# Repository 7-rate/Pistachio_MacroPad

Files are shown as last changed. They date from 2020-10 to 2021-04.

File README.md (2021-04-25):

# Pistachio_MacroPad

[PistachioMacroPad](https://rates.booth.pm/items/2531312)の基板情報。

## 回路図
回路図は[こちら](./Pistachio_MacroPad_rev1.0/schema.pdf)<br>
必要な電子部品も上記から確認お願いします。

## 機械パーツ
ねじやスペーサなどのパーツはPistachioMacroPadと同じです。
Boothページよりご確認ください。

## プレート類
トッププレート、ボトムプレートの設計図面は[こちら](./CAD)

## ビルドガイド
PistachioMacroPadとほぼ同じです。<br>
[こちら](https://ratelog.net/pistachiomacropad-build-guide/)からご確認お願いします。

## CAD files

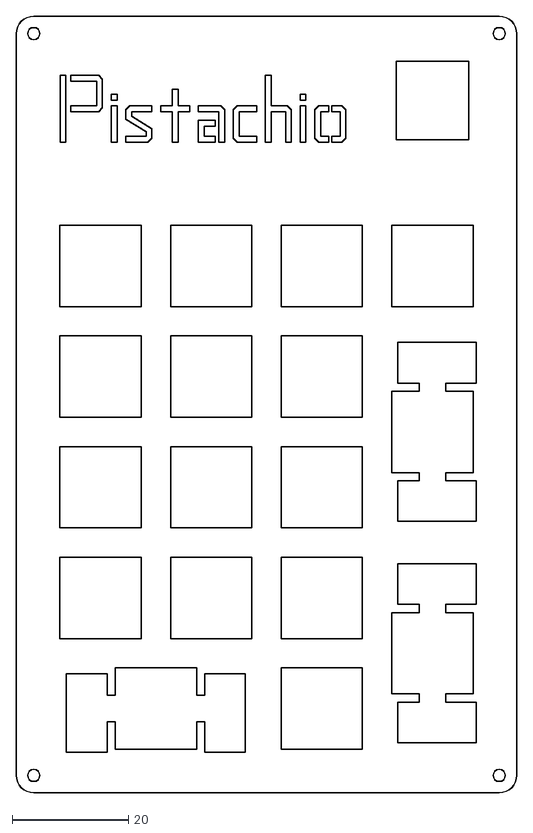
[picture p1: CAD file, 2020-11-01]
CAD/Plate_v2.dxf
86.1 x 133.7

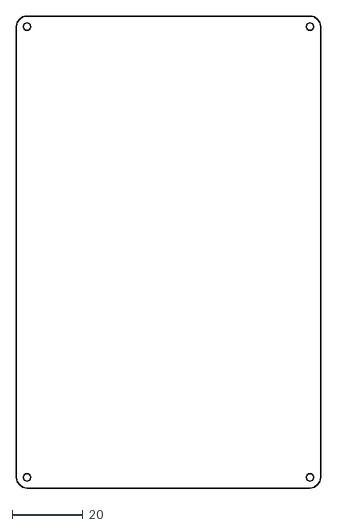
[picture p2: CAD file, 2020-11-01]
CAD/bottom.dxf
86.1 x 133.7

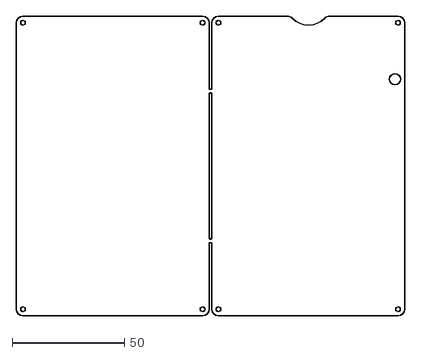
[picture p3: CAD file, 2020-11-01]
CAD/PCB_base_v2.dxf
173.3 x 133.7

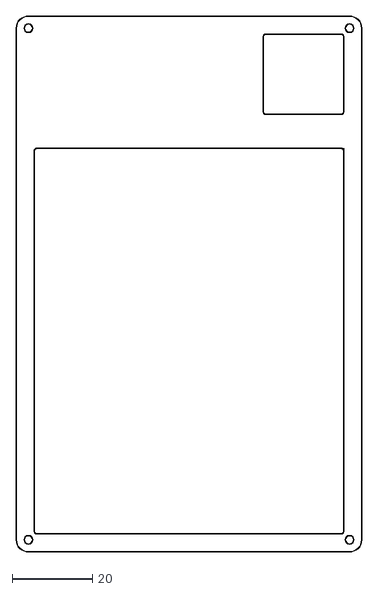
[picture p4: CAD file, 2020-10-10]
CAD/Top.dxf
86.1 x 133.7

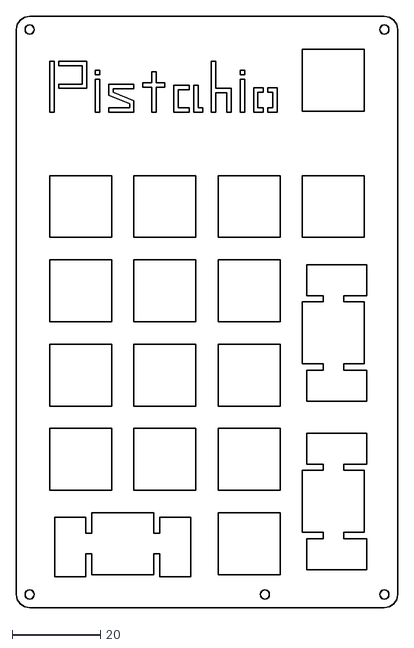
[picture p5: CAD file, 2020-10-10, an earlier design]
CAD/Plate.dxf
86.1 x 133.7

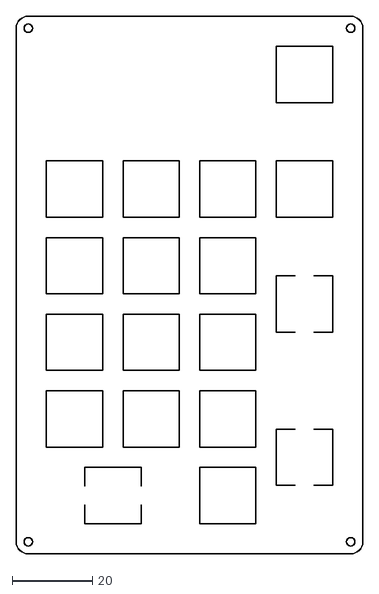
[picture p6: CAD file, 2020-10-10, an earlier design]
CAD/PCB_base.dxf
86.1 x 133.7

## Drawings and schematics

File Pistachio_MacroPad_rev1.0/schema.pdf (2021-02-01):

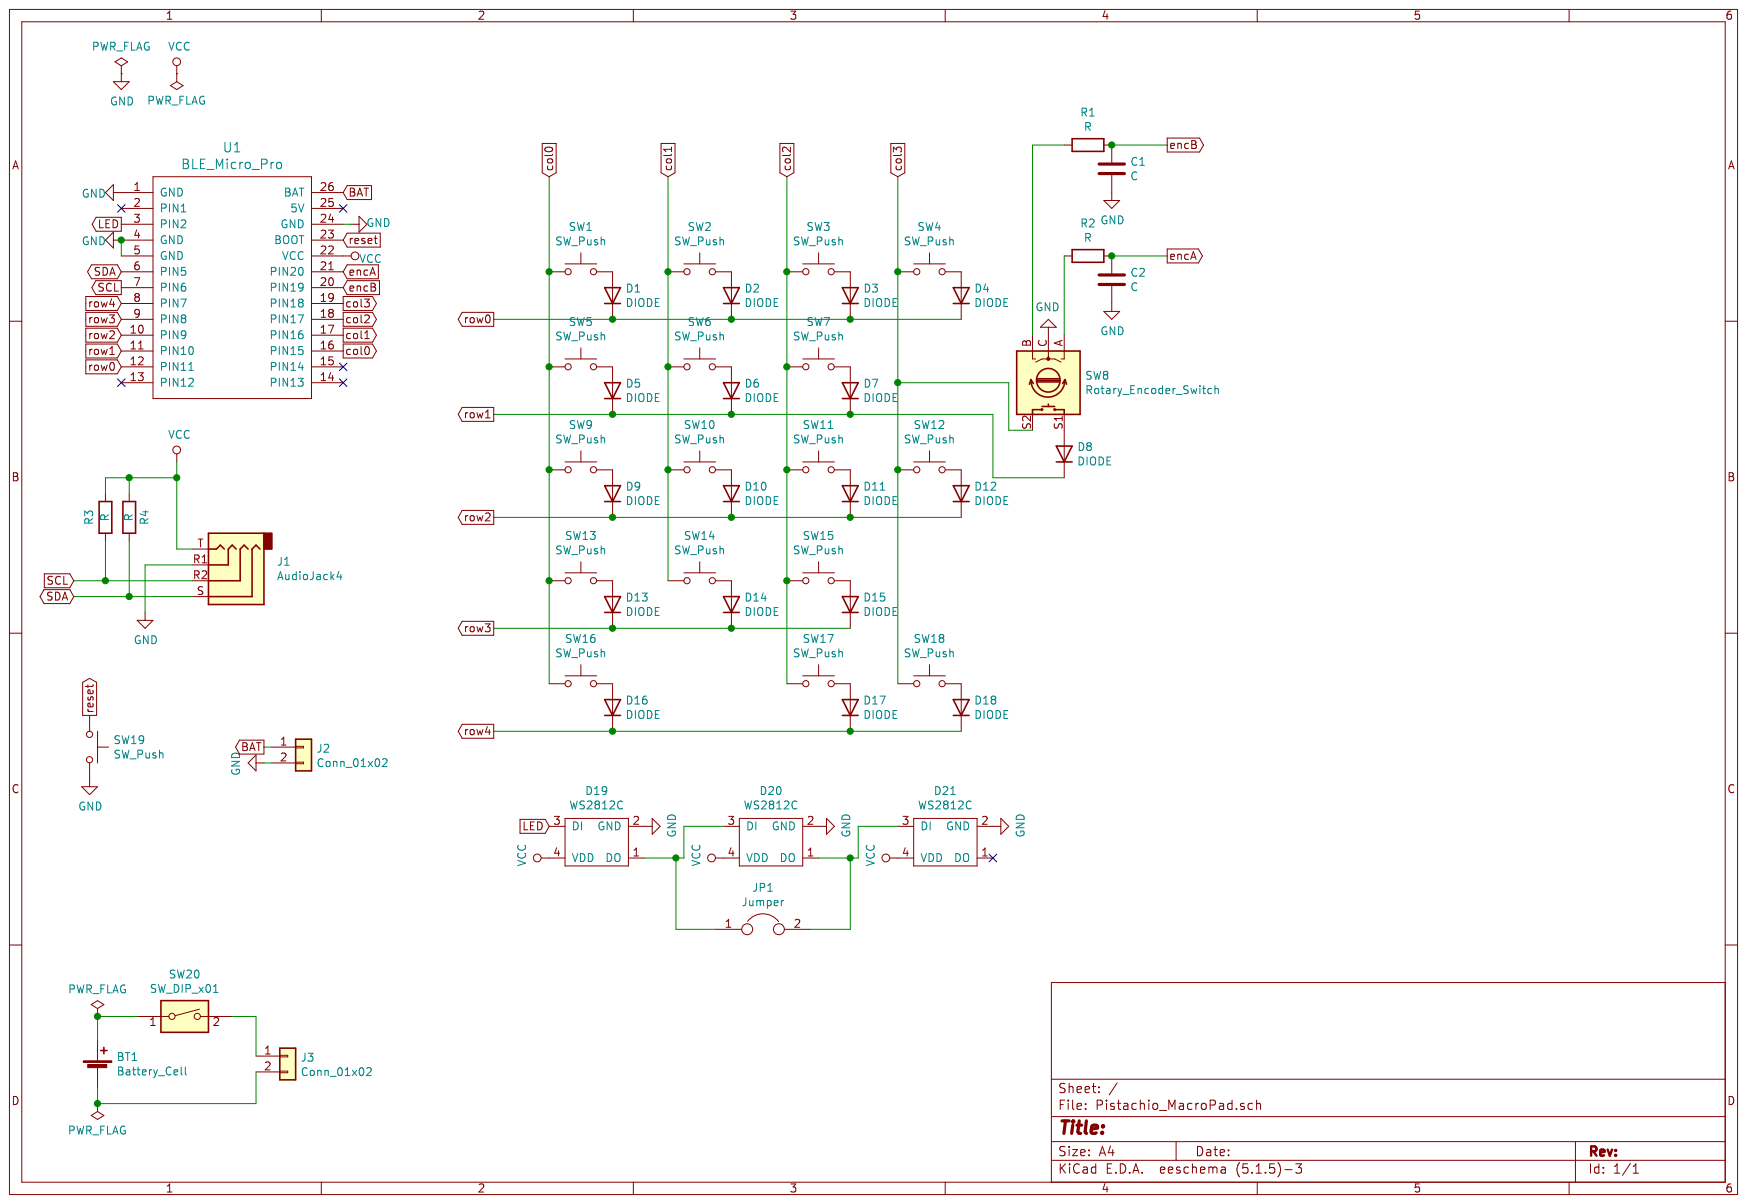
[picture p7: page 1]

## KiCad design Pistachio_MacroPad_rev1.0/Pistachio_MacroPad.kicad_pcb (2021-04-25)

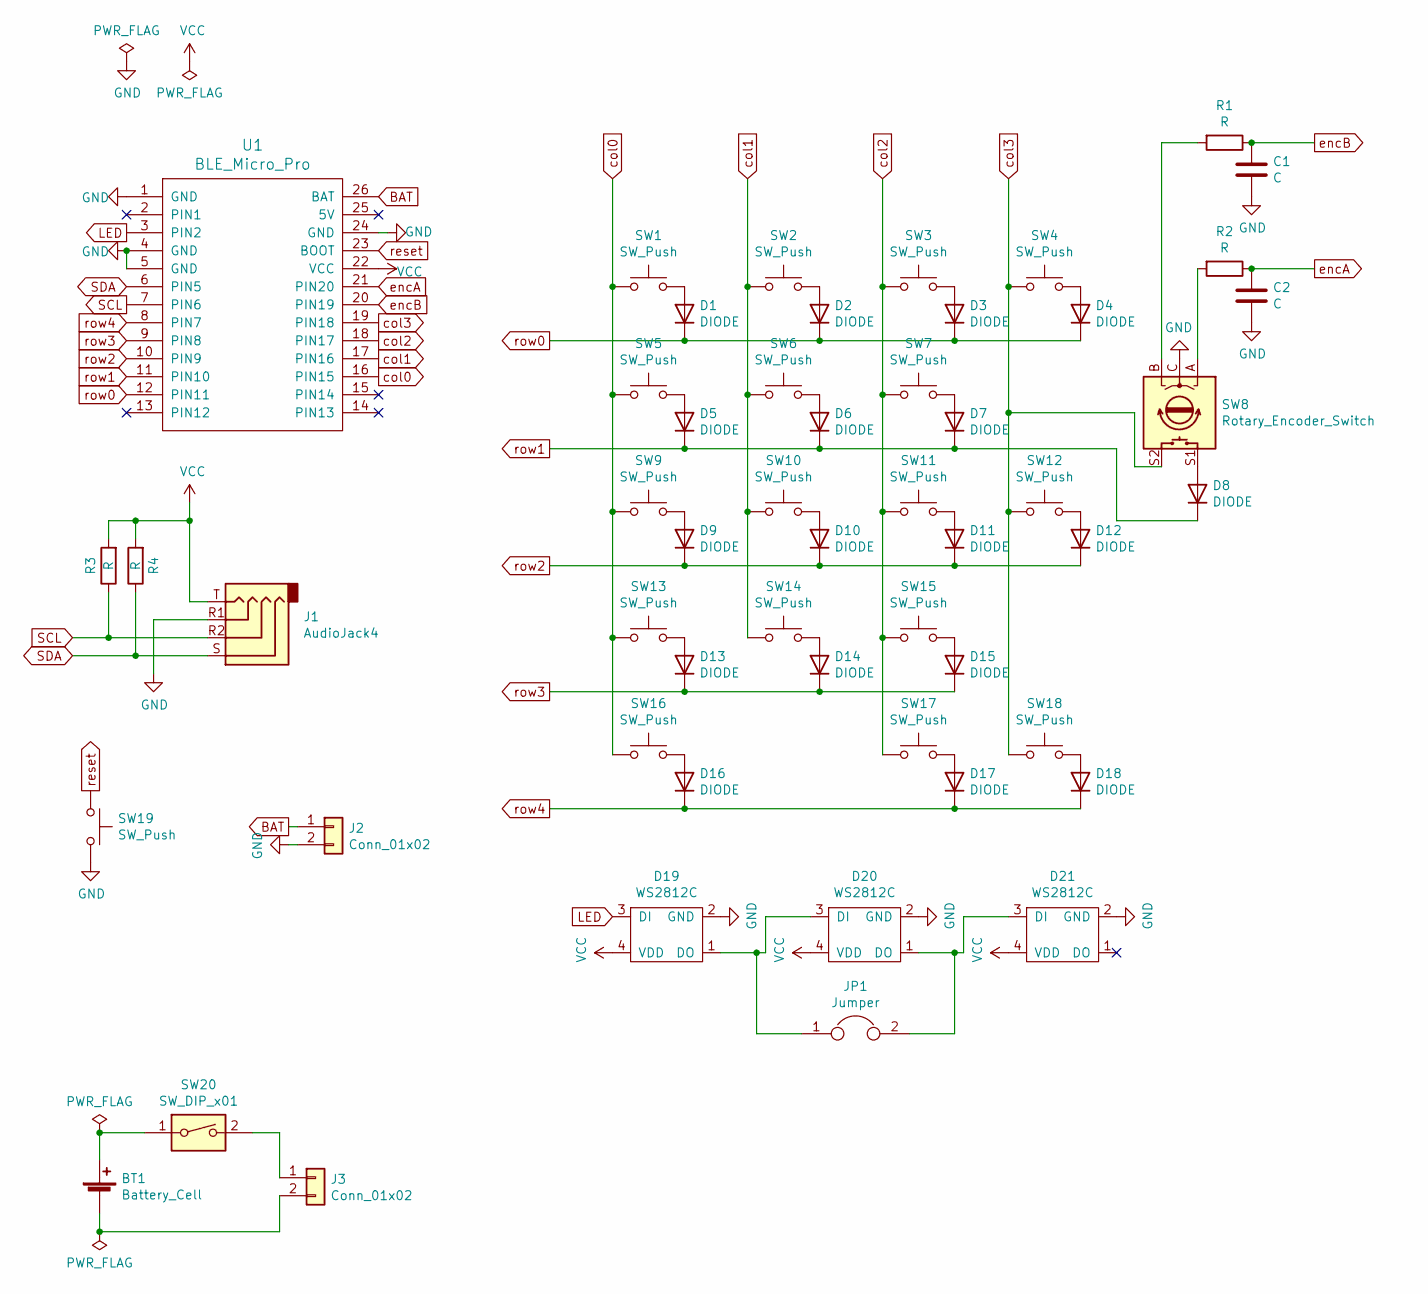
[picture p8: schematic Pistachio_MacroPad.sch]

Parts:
BT1: Battery_Cell; BAT_HLD-001
C1, C2: C; C_0603_1608Metric_Pad1.05x0.95mm_HandSolder
D1, D2, D3, D4, D5, D6, D7, D8, D9, D10, D11, D12, D13, D14, D15, D16, D17, D18: DIODE; D3_SMD_v2
D19, D20, D21: WS2812C; WS2812C-2020
J1: AudioJack4; MJ-4PP-9_1side
J2: Conn_01x02; S2B-ZR-3.4
J3: Conn_01x02; POWER_PAD
JP1: Jumper; SolderJumper-2_P1.3mm_Open_RoundedPad1.0x1.5mm
R1, R2, R3, R4: R; R_0603_1608Metric_Pad1.05x0.95mm_HandSolder
SW1, SW2, SW3, SW4, SW5, SW6, SW7, SW9, SW10, SW11, SW12, SW13, SW14, SW15, SW16, SW17, SW18: SW_Push; Kailh_socket_MX_optional
SW8: Rotary_Encoder_Switch; PEC12R-4xxxF-Sxxxx
SW19: SW_Push; ResetSW_1side
SW20: SW_DIP_x01; SlideSwitch_IS-2245S-G
U1: BLE_Micro_Pro; ProMicro_BLE

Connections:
BAT: J2.1, U1.26 (BAT)
GND: C1.2, C2.2, D19.2 (GND), D20.2 (GND), D21.2 (GND), J1.R1, J2.2, SW8.C, SW19.2, U1.1 (GND), U1.4 (GND), U1.5 (GND), U1.24 (GND)
LED: D19.3 (DI), U1.3 (PIN2)
unnamed: BT1.1 (+), SW20.1
unnamed: BT1.2 (-), J3.2
unnamed: D1.1 (A), SW1.2
unnamed: D2.1 (A), SW2.2
unnamed: D3.1 (A), SW3.2
unnamed: D4.1 (A), SW4.2
unnamed: D5.1 (A), SW5.2
unnamed: D6.1 (A), SW6.2
unnamed: D7.1 (A), SW7.2
unnamed: D8.1 (A), SW8.S1
unnamed: D9.1 (A), SW9.2
unnamed: D10.1 (A), SW10.2
unnamed: D11.1 (A), SW11.2
unnamed: D12.1 (A), SW12.2
unnamed: D13.1 (A), SW13.2
unnamed: D14.1 (A), SW14.2
unnamed: D15.1 (A), SW15.2
unnamed: D16.1 (A), SW16.2
unnamed: D17.1 (A), SW17.2
unnamed: D18.1 (A), SW18.2
unnamed: D19.1 (DO), D20.3 (DI), JP1.1
unnamed: D20.1 (DO), D21.3 (DI), JP1.2
unnamed: J3.1, SW20.2
unnamed: R1.2, SW8.B
unnamed: R2.2, SW8.A
SCL: J1.R2, R3.1, U1.7 (PIN6)
SDA: J1.S, R4.1, U1.6 (PIN5)
VCC: D19.4 (VDD), D20.4 (VDD), D21.4 (VDD), J1.T, R3.2, R4.2, U1.22 (VCC)
col0: SW1.1, SW5.1, SW9.1, SW13.1, SW16.1, U1.16 (PIN15)
col1: SW2.1, SW6.1, SW10.1, SW14.1, U1.17 (PIN16)
col2: SW3.1, SW7.1, SW11.1, SW15.1, SW17.1, U1.18 (PIN17)
col3: SW4.1, SW8.S2, SW12.1, SW18.1, U1.19 (PIN18)
encA: C2.1, R2.1, U1.21 (PIN20)
encB: C1.1, R1.1, U1.20 (PIN19)
reset: SW19.1, U1.23 (BOOT)
row0: D1.2 (K), D2.2 (K), D3.2 (K), D4.2 (K), U1.12 (PIN11)
row1: D5.2 (K), D6.2 (K), D7.2 (K), D8.2 (K), U1.11 (PIN10)
row2: D9.2 (K), D10.2 (K), D11.2 (K), D12.2 (K), U1.10 (PIN9)
row3: D13.2 (K), D14.2 (K), D15.2 (K), U1.9 (PIN8)
row4: D16.2 (K), D17.2 (K), D18.2 (K), U1.8 (PIN7)

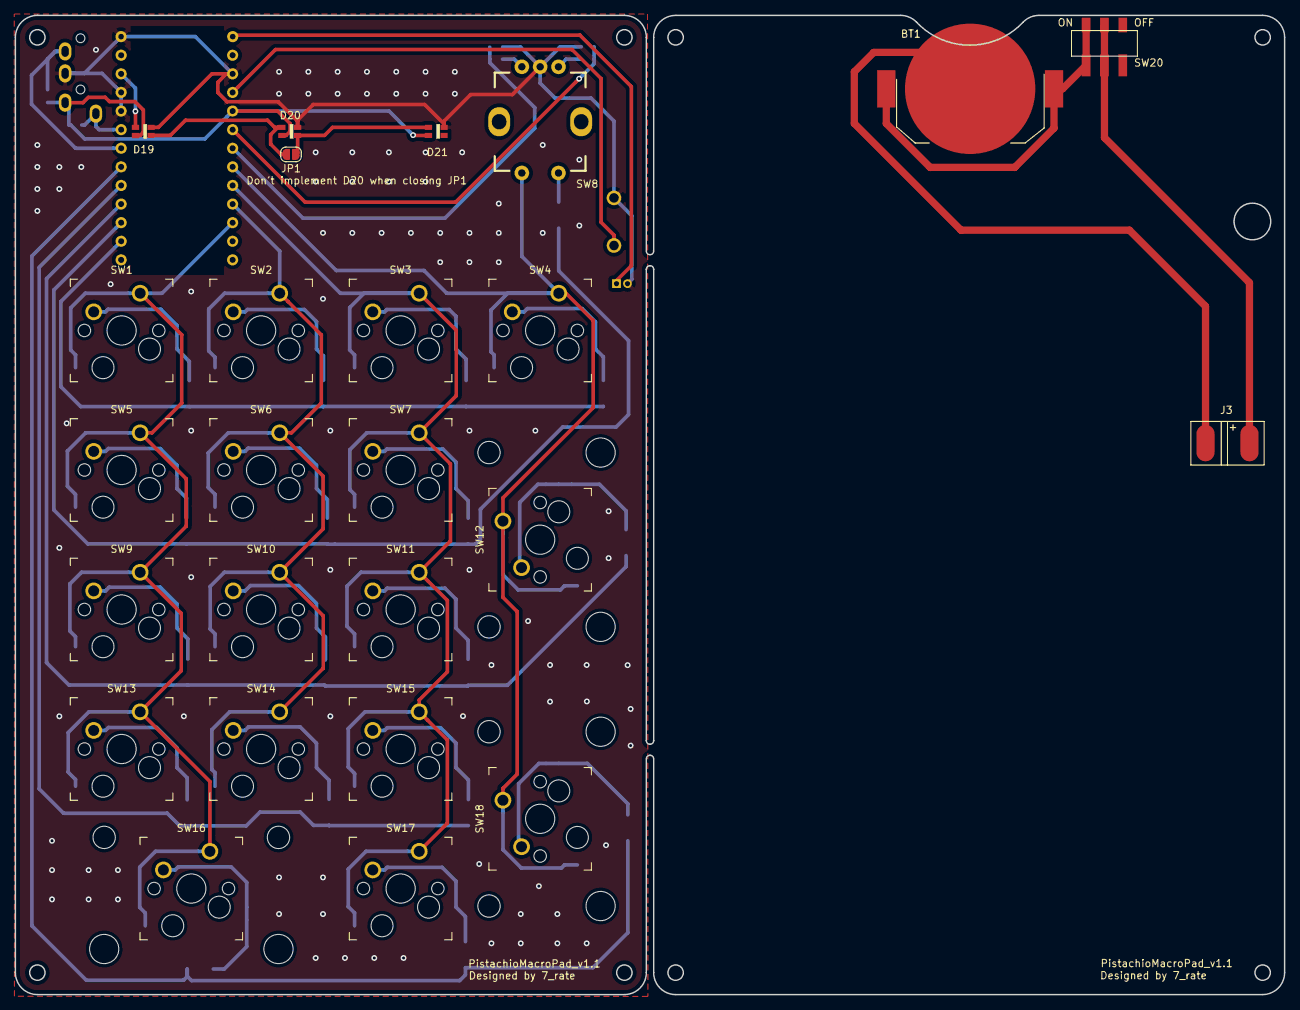
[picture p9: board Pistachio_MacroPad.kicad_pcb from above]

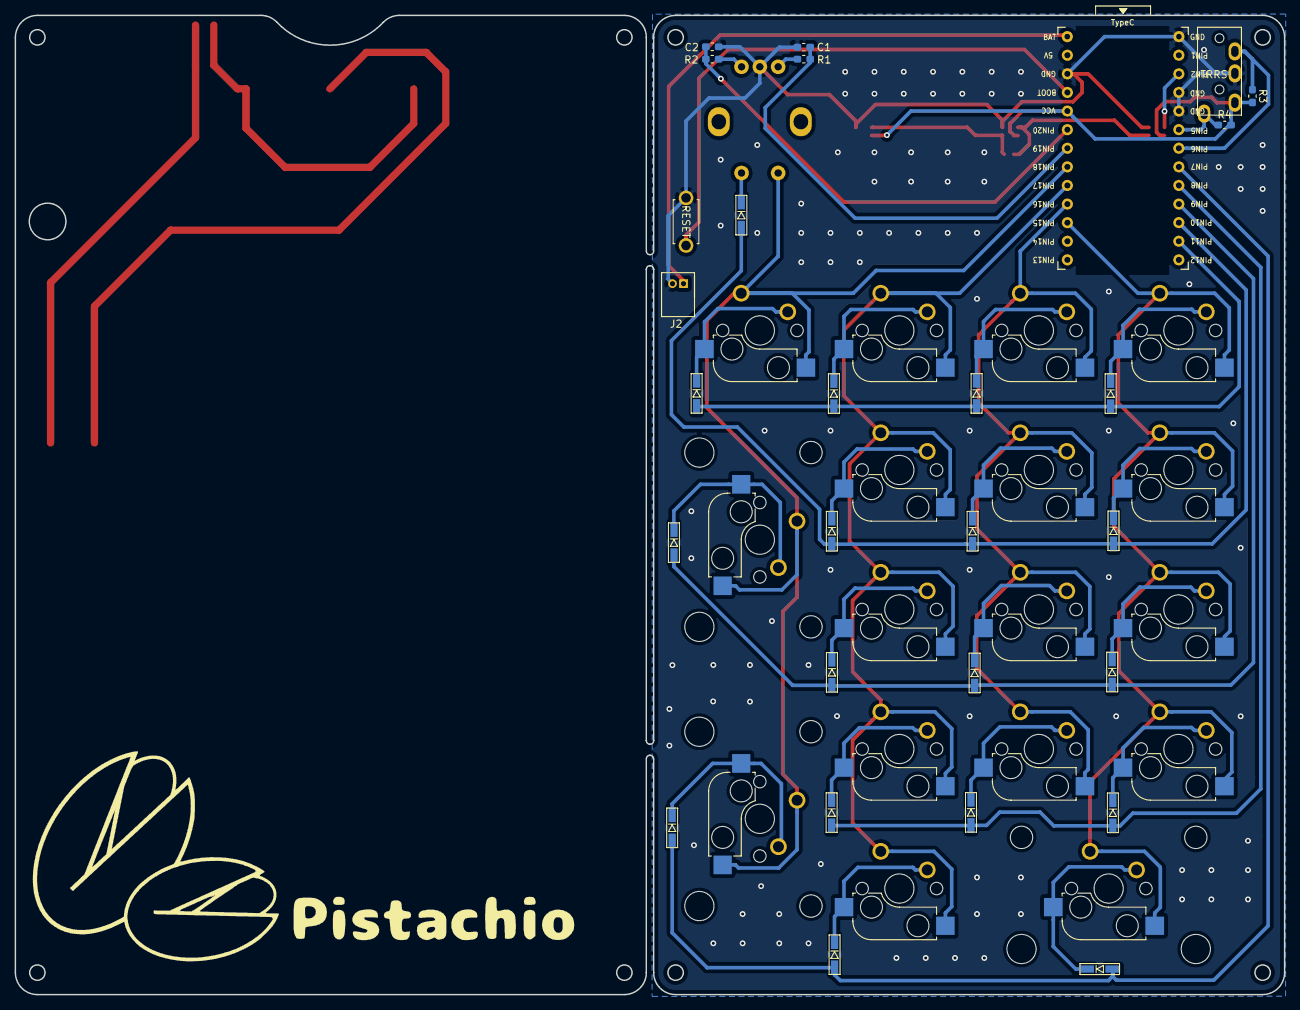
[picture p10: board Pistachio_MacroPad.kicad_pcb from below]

Board: 2 copper layers, 173.3 x 133.7 mm, 53 parts (28 on the bottom side), 43 nets.

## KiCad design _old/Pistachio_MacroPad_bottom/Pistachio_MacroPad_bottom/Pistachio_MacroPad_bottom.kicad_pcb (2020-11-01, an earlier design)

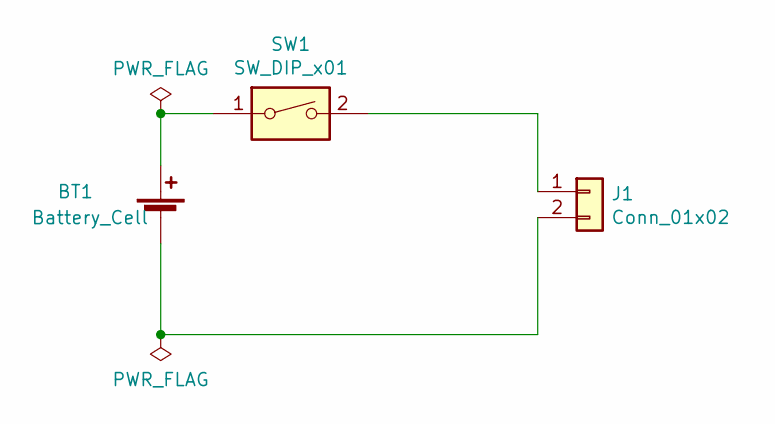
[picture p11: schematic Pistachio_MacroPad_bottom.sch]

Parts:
BT1: Battery_Cell; BAT_HLD-001
J1: Conn_01x02; POWER_PAD
SW1: SW_DIP_x01; SlideSwitch_IS-2245S-G

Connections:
unnamed: BT1.1 (+), SW1.1
unnamed: BT1.2 (-), J1.2
unnamed: J1.1, SW1.2

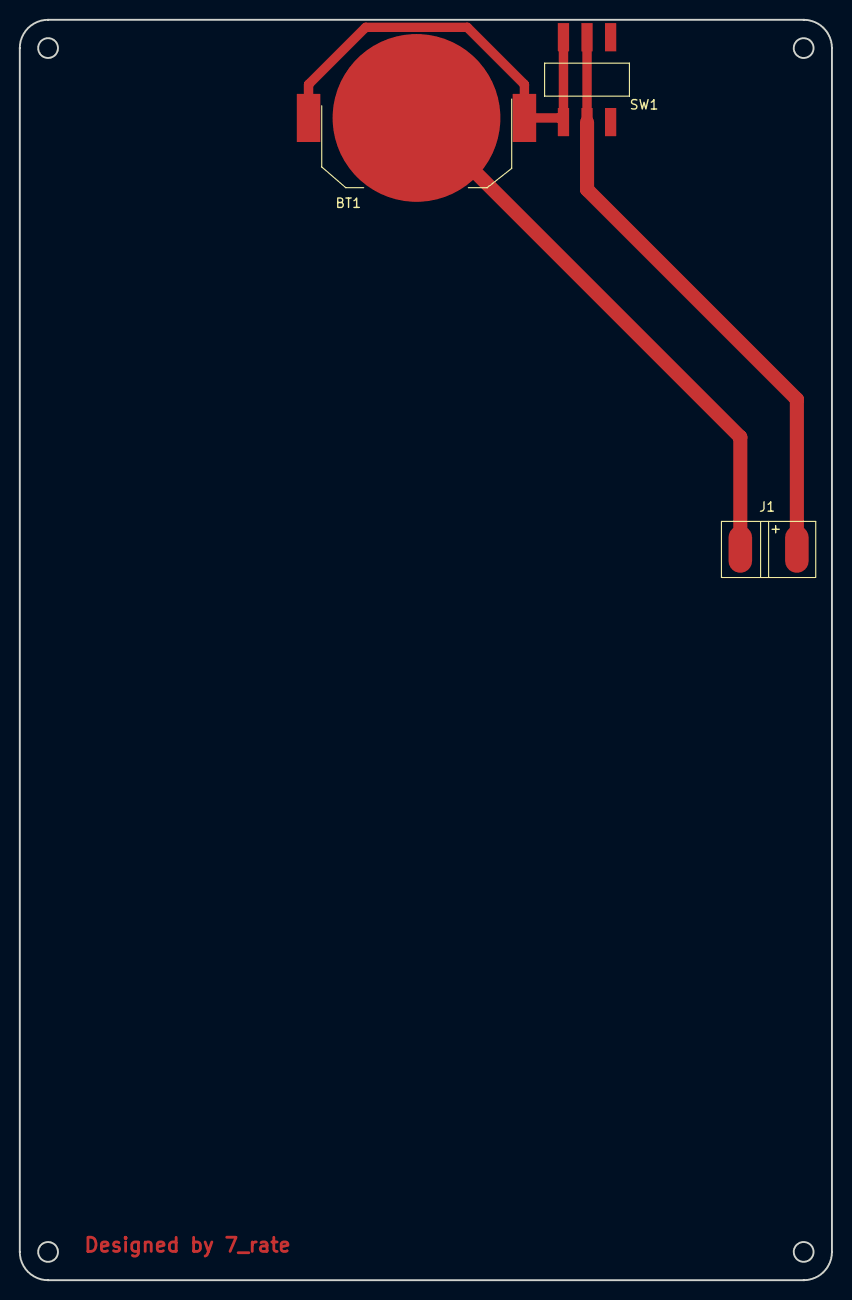
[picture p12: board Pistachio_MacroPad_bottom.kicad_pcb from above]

Board: 2 copper layers, 86.1 x 133.7 mm, 3 parts (0 on the bottom side), 3 nets.

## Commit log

2020-10-10 基板設計完了
    [PCB_base.dxf, Pistachio_MacroPad.kicad_pcb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]
2020-11-01 サブモジュールを更新
2020-11-28 デフォルトキーマップを追加
2021-02-01 回路図更新
2021-04-25 フォルダ構造整理
    [Pistachio_MacroPad.kicad_pcb, Pistachio_MacroPad.sch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]
